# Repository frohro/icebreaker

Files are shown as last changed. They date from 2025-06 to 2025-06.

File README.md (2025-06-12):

# iCEBreaker FPGA

This repository is to update the Bitsy 1.1c so it has JLCPCB part numbers and can be ordered.

 

The iCEBreaker FPGA board is a low cost, open-source educational FPGA
development board.

The main motivating application of this board is for classes and workshops
teaching the use of the open source FPGA design flow using
[Yosys](http://www.clifford.at/yosys/),
[nextpnr](https://github.com/YosysHQ/nextpnr),
[icestorm](http://www.clifford.at/icestorm/),
[iverilog](http://iverilog.icarus.com/),
[symbiflow](https://github.com/SymbiFlow) and others. This means the board has
to be low cost and have a nice set of features to allow for the design of
interesting classes and workshop exercises. At the same time we want to allow
the user to use the proprietary vendor tools if they choose to. Because of that
we need to be compatible with their firmware upload tools.

## iCEBreaker Hardware Specifications

* iCE40UP5K in QFN48 (SG48) package
  * [iCE40 UltraPlus 5K](http://www.latticesemi.com/-/media/LatticeSemi/Documents/DataSheets/iCE/iCE40-UltraPlus-Family-Data-Sheet.ashx)
  * 5280 Logic Cells (4-LUT + Carry + FF)
  * 128 KBit Dual-Port Block RAM
  * 1 MBit (128 KB) Single-Port RAM
  * PLL, Two SPI and two I2C hard IPs
  * Two internal oscillators (10 kHz and 48 MHz)
  * 8 DSPs (16x16 multiply + 32 bit accumulate)
  * 3x 24mA drive and 3x hard PWM IP

* QSPI-DDR-capable flash 128 MBit (16 MB)
  * We selected to use the Winbond
    [W25Q128JVSIM](http://www.winbond.com/resource-files/w25q128jv_dtr%20revc%2003272018%20plus.pdf)
  * We want to enable projects that access the flash and we want to provide the
    highest flash access speed possible.

* [FT2232H](http://www.ftdichip.com/Support/Documents/DataSheets/ICs/DS_FT2232H.pdf) interface (microUSB plug)
  * programming compatible with iCEstick and HX8K board
    * works with [Dimond Programmer](http://www.latticesemi.com/programmer) and
      [iceprog](https://github.com/cliffordwolf/icestorm/tree/master/iceprog)
  * serial port compatible with iCEstick and HX8K breakout board
  * 12 MHz XTAL oscillator (shared with FPGA)
  * Solder jumpers to offer direct SRAM programming (like on HX8K breakout board)

* 39 I/O capable pins:
  * 4 pins for config (SDI, SDO, SCK, CSB)
    * Either loading config from on board FLASH chip or provided through the
      FTDI chip with direct SRAM config.
  * 2 extra GPIO pins for QSPI
    * Together with the config pins, allows storage of additional data in the
      FLASH chip, and high speed QSPI DDR access. For example
      [picosoc](https://github.com/cliffordwolf/picorv32/tree/master/picosoc)
      firmware.
  * 3 PINs for RGB LED (pin header)
  * 2 LEDs (one on output-only PLL pin)
  * 1 Clock pin (on PLL GBIN)
  * 1 UART Rx Pin via FTDI
  * 1 UART Tx Pin via FTDI
  * 1 Push Button
  * 16 PINs on dual PMOD
  * 8 PINs on single PMOD / snap-off section

* Support for FTDI Async FIFO mode
  * We want to support FTDI Async mode via some (unpopulated by default) zero
    ohm resistors
  * This shares 8 GPIOs with the single PMOD / snap-off section
  * This would also enable use of full list of RS232 signals
  * BDATA[0] -- Tx on FTDI / Rx on FPGA (always connected, no zohm resistor
    required)
  * BDATA[1] -- Rx on FTDI / Tx on FPGA (always connected, no zohm resistor
    required)
  * BDATA[7:2] -- Shared with snap-off section (via zohm resistor footprint)
  * RX Full -- Shared with snap-off section (via zohm resistor footprint)
  * TX Empty -- Shared with snap-off section (via zohm resistor footprint)
  * Read -- Shared with LED 1 (via zohm resistor footprint, LED used as RX
    indicator)
  * Write -- Shared with LED 2 (via zohm resistor footprint, LED used as TX
    indicator)
  * WakeUp -- Shared with Push Button (via zohm resistor footprint)
  * This configuration uses the following pins when the jumpers ore reconfigured:
    * The two on board red and green LED pins
    * The on board user button pin
    * snap off section single PMOD pins 

* Snap-off section (convertible to PMOD host / PMOD device)
  * 5 LEDs in similar arrangement to iCEstick
  * 3 Push Buttons

* Other stuff
  * Status LEDs for Power and CDONE (Configuration DONE)
  * Header with supply rails: 5V, 3V3, 1V2, GND
  * Debug header for all 6 QSPI pins
  * Test points for UART Rx / Tx signals
  * Jumpers or zohm resistors on all rails for measuring currents
  * Four 3mm mounting holes on the main section and two more on the snap-off
    section
  * The two LEDs on the main section should be wired "active low" so they work 
    well as indicator LEDs for FIFO read/write.
  * The five LEDs on the snap-off section should be wired "active high"
  * A zohm resistor for Bank 2 supply so that the IO voltage can be changed. Use
    Bank 2 for one of the ports on the double PMOD.
  * There should be auxilary 5V pin headers available for the PMODs. Some PMOD
    need either higher voltage or need to regulate their own voltage from 5V.

* Unpopulated parts shipped with the board
  * 3x Host PMOD (2x for dual PMOD port, 1x for snap-off section)
  * 1x Device PMOD (for other side of snap-off section)

iCEBreaker block diagram
**iCEBreaker block diagram**  
iCEBreaker V1.0b pinout legend
**iCEBreaker V1.0b pinout legend**  
iCEBreaker V1.0b jumper legend
**iCEBreaker V1.0b jumper legend**  

## iCEBreaker Bitsy

iCEBreaker Bitsy is the smaller but just-as-capable sibling to iCEBreaker. At just 36x18mm, it is compatible with the Teensy form-factor and can be easily embedded into any project.

iCEBreaker Bitsy v1.1b panel photo

* iCE40UP5K in QFN48 (SG48) package
  * PLL, two SPI and two I2C hard IPs
* 128M (16MiB) DDR- and QPI-capable Flash Memory
* 64M (8MiB) QPI-capable Pseudo-SRAM
* USB-C interface (comes preloaded with a [RISC-V soft-core USB bootloader](//github.com/no2fpga/no2bootloader))
* RGB LED connected to 3x 24mA hard PWM IP pins
* Two user LEDs (one shared with RAM-CS)
* Status LED for CDONE (Configuration DONE)
* 12MHz external clock (on PLL GBIN)
* One user button
* Supply rails: 3.3V and 1.2V
* FPGA SPI/programming header
  * 4 pins for config (SDI, SDO, SCK, CS)
  * 2 extra GPIO pins for QSPI/QPI
  * CDONE (Configuration DONE), CRESET (Configuration RESET), 3.3V, and GND
* Teensy form-factor compatible
* Compatible with Feather ecosystem using a [Teensy 3.x Feather Adapter](//adafruit.com/product/3200)
* Castellated edges and single-side-load for easy module integration

iCEBreaker Bitsy v1.1c info card, front
iCEBreaker Bitsy v1.1c info card, back

## Branding

[iCEbreaker](https://twitter.com/AboveVacant/status/948323920595308545)

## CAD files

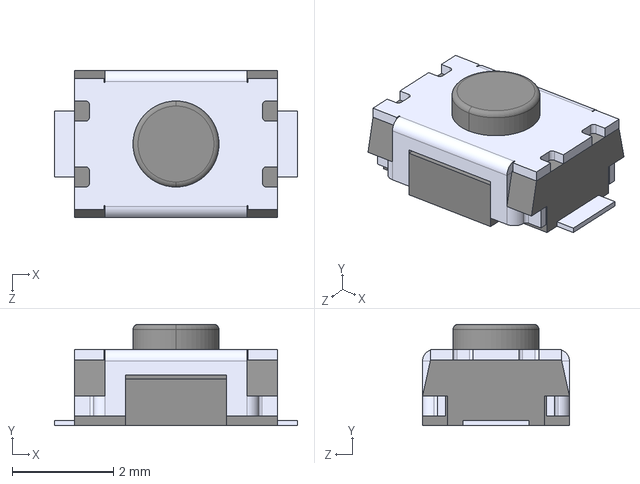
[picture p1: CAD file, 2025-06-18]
hardware/bitsy-v1.1c/TS-1088-AR02016--3DModel-STEP-269445.STEP
4.80 x 2.00 x 2.90 mm

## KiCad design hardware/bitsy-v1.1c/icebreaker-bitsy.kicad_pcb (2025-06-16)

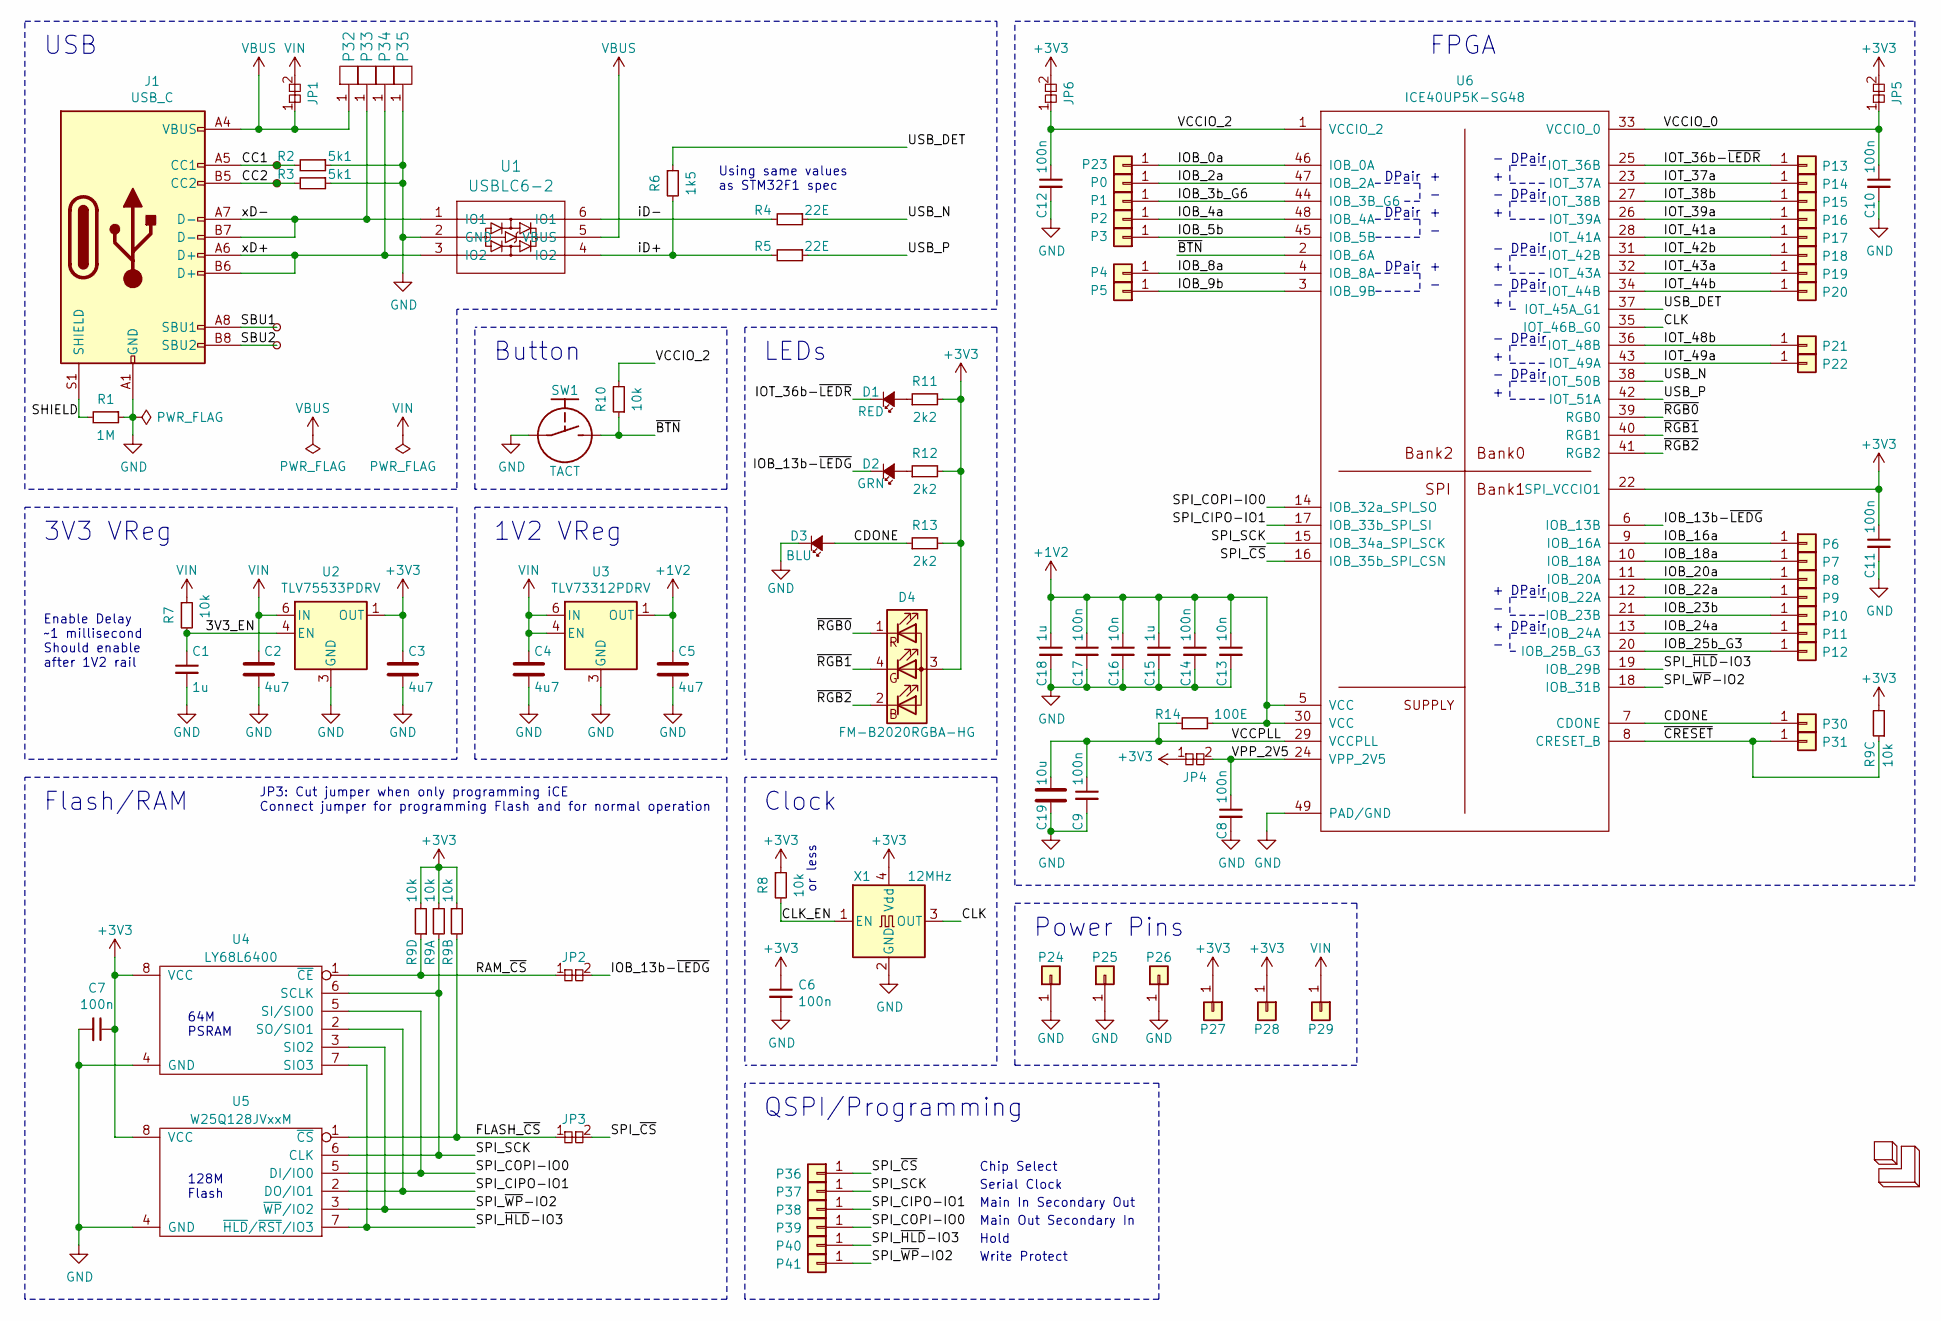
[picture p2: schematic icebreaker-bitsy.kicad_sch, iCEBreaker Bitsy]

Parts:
C1, C15, C18: 1u; C_0402; LCSC C52923
C2, C3, C4, C5: 4u7; C_0603
C6, C7, C8, C9, C10, C14, C17: 100n; C_0402; LCSC C1525
C11: 100n; C_0402
C12: 100n; C_0402_1005Metric; LCSC C1525
C13, C16: 10n; C_0402; LCSC C15195
C19: 10u; C_0603; LCSC C19702
D1: RED; D_0603; LCSC C2286
D2: GRN; D_0603; LCSC C19171392
D3: BLU; D_0603; LCSC C19171394
D4: FM-B2020RGBA-HG; LED_TRI_2020; LCSC C42421005
J1: USB_C; USB_C_Receptacle_HRO_TYPE-C-31-M-12; LCSC C2765186
JP1: VIN-VBUS; J_NC_0603_40
JP2: RAM_CS-LEDG; J_NC_0402_15
JP3: Flash_CS-SPI_CS; J_NC_0402_15
JP4: Vpp2v5; J_NC_0402_30
JP5: VccIO0; J_NC_0603_30
JP6: VccIO2; J_NC_0603_30
LOGO1: 1BitSquared; 1b2_Logo_SilkS_2mm
P0: 0; Pin_Header_Straight_Round_1x01_Castellated
P1: 1; Pin_Header_Straight_Round_1x01_Castellated
P2: 2; Pin_Header_Straight_Round_1x01_Castellated
P3: 3; Pin_Header_Straight_Round_1x01_Castellated
P4: 4; Pin_Header_Straight_Round_1x01_Castellated
P5: 5; Pin_Header_Straight_Round_1x01_Castellated
P6: 6; Pin_Header_Straight_Round_1x01_Castellated
P7: 7; Pin_Header_Straight_Round_1x01_Castellated
P8: 8; Pin_Header_Straight_Round_1x01_Castellated
P9: 9; Pin_Header_Straight_Round_1x01_Castellated
P10: 10; Pin_Header_Straight_Round_1x01_Castellated
P11: 11; Pin_Header_Straight_Round_1x01_Castellated
P12: 12; Pin_Header_Straight_Round_1x01_Castellated
P13: 13; Pin_Header_Straight_Round_1x01_Castellated
P14: 14; Pin_Header_Straight_Round_1x01_Castellated
P15: 15; Pin_Header_Straight_Round_1x01_Castellated
P16: 16; Pin_Header_Straight_Round_1x01_Castellated
P17: 17; Pin_Header_Straight_Round_1x01_Castellated
P18: 18; Pin_Header_Straight_Round_1x01_Castellated
P19: 19; Pin_Header_Straight_Round_1x01_Castellated
P20: 20; Pin_Header_Straight_Round_1x01_Castellated
P21: 21; Pin_Header_Straight_Round_1x01_Castellated
P22: 22; Pin_Header_Straight_Round_1x01_Castellated
P23: 23; Pin_Header_Straight_Round_1x01_Castellated
P24, P25, P26: GND; Pin_Header_Straight_Round_1x01_Castellated
P27, P28: 3V3; Pin_Header_Straight_Round_1x01_Castellated
P29: VIN; Pin_Header_Straight_Round_1x01_Castellated
P30: CDONE; Pin_Header_Straight_Round_1x01_Castellated
P31: CRESET; Pin_Header_Straight_Round_1x01_Castellated
P32, P33, P34, P35: UP; PAD_SMD_1x2.65_ROUNDED
P36: CS; Pin_Header_Straight_Round_1x01
P37: SCK; Pin_Header_Straight_Round_1x01
P38: CIPO; Pin_Header_Straight_Round_1x01
P39: COPI; Pin_Header_Straight_Round_1x01
P40: IO3; PAD_SMD_R_1x1
P41: IO2; PAD_SMD_R_1x1
R1: 1M; R_0402; LCSC C26083
R2, R3: 5k1; R_0402; LCSC C25905
R4: 22E; R_0402; LCSC C25092
R5: 22E; R_0402_1005Metric; LCSC C25092
R6: 1k5; R_0402; LCSC C25867
R7, R8, R10: 10k; R_0402; LCSC C25744
R9: 10k; R_Array_Convex_4x0402; LCSC C326872
R11: 2k2; R_0402; LCSC C25879
R12, R13: 2k2; R_0402_1005Metric; LCSC C25879
R14: 100E; R_0402; LCSC C25076
SW1: TACT; TS-1088-AR02016; LCSC C720477
TP1: CC1; TestPoint_Pad_D0.75mm
TP2: CC2; TestPoint_Pad_D0.75mm
TP3: SBU1; TestPoint_Pad_D0.75mm
TP4: SBU2; TestPoint_Pad_D0.75mm
U1: USBLC6-2; SOT-666; LCSC C7519
U2: TLV75533PDRV; WSON-6-1EP_2x2mm_P0.65mm_EP1x1.6mm; LCSC C2861750
U3: TLV73312PDRV; WSON-6-1EP_2x2mm_P0.65mm_EP1x1.6mm; LCSC C2863369
U4: LY68L6400; SOIC-8_3.9x4.9mm_P1.27mm; LCSC C261881
U5: W25Q128JVxxM; WSON-8-1EP_6x5mm_P1.27mm_EP3.4x4.3mm; LCSC C2441427
U6: ICE40UP5K-SG48; QFN-48-1EP_7x7mm_Pitch0.5mm
X1: 12MHz; Oscillator_SMD_SCTF_S2DXX-4Pin_2.5x2.0mm; LCSC C9002

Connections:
+1V2: C5.1, C13.1, C14.1, C15.1, C16.1, C17.1, C18.1, R14.2, U3.1 (OUT), U6.5 (VCC), U6.30 (VCC)
+3V3: C3.1, C6.1, C7.1, C11.1, D4.3 (A), JP4.1, JP5.2, JP6.2, P27.1, P28.1, R8.1, R9.1, R9.3, R9.6, R9.8, R11.2, R12.2, R13.2, U2.1 (OUT), U4.8 (VCC), U5.8 (VCC), U6.22 (SPI_VCCIO1), X1.4 (Vdd)
/3V3_EN: C1.1, R7.2, U2.4 (EN)
/CC1: J1.A5 (CC1), R2.2, TP1.1
/CC2: J1.B5 (CC2), R3.2, TP2.1
/CDONE: D3.A, P30.1, R13.1, U6.7 (CDONE)
/CLK: U6.35 (IOT_46B_G0), X1.3 (OUT)
/CLK_EN: R8.2, X1.1 (EN)
/FLASH_~CS: JP3.1, R9.4, U5.1 (~CS)
/IOB_0a: P23.1, U6.46 (IOB_0A)
/IOB_2a: P0.1, U6.47 (IOB_2A)
/IOB_3b_G6: P1.1, U6.44 (IOB_3B_G6)
/IOB_4a: P2.1, U6.48 (IOB_4A)
/IOB_5b: P3.1, U6.45 (IOB_5B)
/IOB_8a: P4.1, U6.4 (IOB_8A)
/IOB_9b: P5.1, U6.3 (IOB_9B)
/IOB_13b-~LEDG: D2.C, JP2.2, U6.6 (IOB_13B)
/IOB_16a: P6.1, U6.9 (IOB_16A)
/IOB_18a: P7.1, U6.10 (IOB_18A)
/IOB_20a: P8.1, U6.11 (IOB_20A)
/IOB_22a: P9.1, U6.12 (IOB_22A)
/IOB_23b: P10.1, U6.21 (IOB_23B)
/IOB_24a: P11.1, U6.13 (IOB_24A)
/IOB_25b_G3: P12.1, U6.20 (IOB_25B_G3)
/IOT_36b-~LEDR: D1.C, P13.1, U6.25 (IOT_36B)
/IOT_37a: P14.1, U6.23 (IOT_37A)
/IOT_38b: P15.1, U6.27 (IOT_38B)
/IOT_39a: P16.1, U6.26 (IOT_39A)
/IOT_41a: P17.1, U6.28 (IOT_41A)
/IOT_42b: P18.1, U6.31 (IOT_42B)
/IOT_43a: P19.1, U6.32 (IOT_43A)
/IOT_44b: P20.1, U6.34 (IOT_44B)
/IOT_48b: P21.1, U6.36 (IOT_48B)
/IOT_49a: P22.1, U6.43 (IOT_49A)
/RAM_~CS: JP2.1, R9.7, U4.1 (~CE)
/SBU1: J1.A8 (SBU1), TP3.1
/SBU2: J1.B8 (SBU2), TP4.1
/SHIELD: J1.S1 (SHIELD), R1.2
/SPI_CIPO-IO1: P38.1, U4.2 (SO/SIO1), U5.2 (DO/IO1), U6.17 (IOB_33b_SPI_SI)
/SPI_COPI-IO0: P39.1, U4.5 (SI/SIO0), U5.5 (DI/IO0), U6.14 (IOB_32a_SPI_SO)
/SPI_SCK: P37.1, R9.2, U4.6 (SCLK), U5.6 (CLK), U6.15 (IOB_34a_SPI_SCK)
/SPI_~CS: JP3.2, P36.1, U6.16 (IOB_35b_SPI_CSN)
/SPI_~HLD-IO3: P40.1, U4.7 (SIO3), U5.7 (~HLD/~RST/IO3), U6.19 (IOB_29B)
/SPI_~WP-IO2: P41.1, U4.3 (SIO2), U5.3 (~WP/IO2), U6.18 (IOB_31B)
/USB_DET: R6.1, U6.37 (IOT_45A_G1)
/USB_N: R4.1, U6.38 (IOT_50B)
/USB_P: R5.1, U6.42 (IOT_51A)
/VCCIO_0: C10.1, JP5.1, U6.33 (VCCIO_0)
/VCCIO_2: C12.1, JP6.1, R10.2, U6.1 (VCCIO_2)
/VCCPLL: C9.1, C19.1, R14.1, U6.29 (VCCPLL)
/VPP_2V5: C8.1, JP4.2, U6.24 (VPP_2V5)
/iD+: R5.2, R6.2, U1.4 (IO2)
/iD-: R4.2, U1.6 (IO1)
/xD+: J1.A6 (D+), J1.B6 (D+), P34.1 (PAD), U1.3 (IO2)
/xD-: J1.A7 (D-), J1.B7 (D-), P33.1 (PAD), U1.1 (IO1)
/~BTN: R10.1, SW1.2, U6.2 (IOB_6A)
/~CRESET: P31.1, R9.5, U6.8 (CRESET_B)
/~RGB0: D4.1 (RK), U6.39 (RGB0)
/~RGB1: D4.4 (GK), U6.40 (RGB1)
/~RGB2: D4.2 (BK), U6.41 (RGB2)
GND: C1.2, C2.2, C3.2, C4.2, C5.2, C6.2, C7.2, C8.2, C9.2, C10.2, C11.2, C12.2, C13.2, C14.2, C15.2, C16.2, C17.2, C18.2, C19.2, D3.C, J1.A1 (GND), J1.A12 (GND), J1.B1 (GND), J1.B12 (GND), P24.1, P25.1, P26.1, P35.1 (PAD), R1.1, R2.1, R3.1, SW1.1, U1.2 (GND), U2.3 (GND), U2.7 (GND), U3.3 (GND), U3.7 (GND), U4.4 (GND), U5.4 (GND), U6.49 (PAD/GND), X1.2 (GND)
unnamed: D1.A, R11.1
unnamed: D2.A, R12.1
VBUS: J1.A4 (VBUS), J1.A9 (VBUS), J1.B4 (VBUS), J1.B9 (VBUS), JP1.1, P32.1 (PAD), U1.5 (VBUS)
VIN: C2.1, C4.1, JP1.2, P29.1, R7.1, U2.6 (IN), U3.4 (EN), U3.6 (IN)

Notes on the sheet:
DPair
1V2 VReg
Using same values as STM32F1 spec
Clock
Main Out Secondary In
Main In Secondary Out
QSPI/Programming
or less
Power Pins
Chip Select
Write Protect
JP3: Cut jumper when only programming iCE Connect jumper for programming Flash and for normal operation
USB
LEDs
Enable Delay ~1 millisecond Should enable after 1V2 rail
64M PSRAM
Hold
128M Flash
3V3 VReg
FPGA
Button
Flash/RAM
Serial Clock

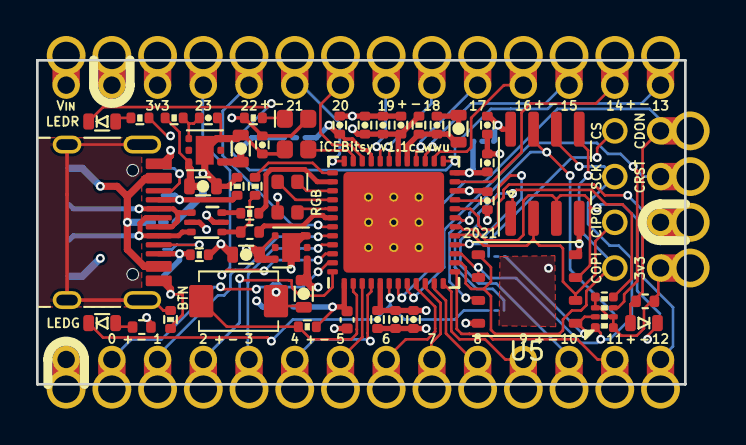
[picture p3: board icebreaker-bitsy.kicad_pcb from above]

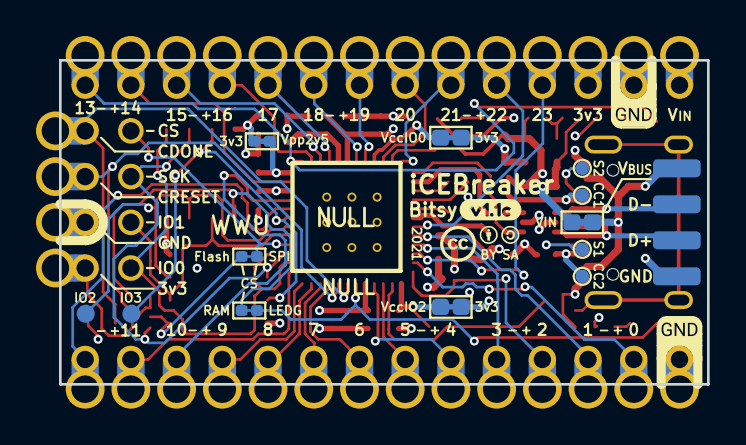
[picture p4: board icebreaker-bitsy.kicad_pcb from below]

Board: 4 copper layers, 36.0 x 18.0 mm, 101 parts (19 on the bottom side), 65 nets.

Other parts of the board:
svg2mod, svg2mod#2, svg2mod#3: G***; svg2mod

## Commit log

2025-06-11 Adding JLCPCB
    [icebreaker-bitsy.kicad_pcb, icebreaker-bitsy.kicad_sch]
2025-06-11 changed some 0402 to use the regular library in Kicad v9
    [icebreaker-bitsy.kicad_pcb]
2025-06-12 PCB changes for JLCPCB parts made.
    [icebreaker-bitsy.kicad_pcb, icebreaker-bitsy.kicad_sch]
2025-06-12 Added 3D models
    [icebreaker-bitsy.kicad_pcb]
2025-06-12 Fixed silkscreen
    [icebreaker-bitsy.kicad_pcb]
2025-06-16 Fixed footprint of U5, etc.
    [icebreaker-bitsy.kicad_pcb, icebreaker-bitsy.kicad_sch]
2025-06-18 Added some footprints
    [TS-1088-AR02016--3DModel-STEP-269445.STEP]

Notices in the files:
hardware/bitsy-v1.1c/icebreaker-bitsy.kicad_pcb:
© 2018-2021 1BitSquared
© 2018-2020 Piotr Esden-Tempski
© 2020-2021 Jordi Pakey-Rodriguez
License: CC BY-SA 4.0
